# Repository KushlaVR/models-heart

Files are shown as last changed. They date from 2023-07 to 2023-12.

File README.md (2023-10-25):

# Model's Heart

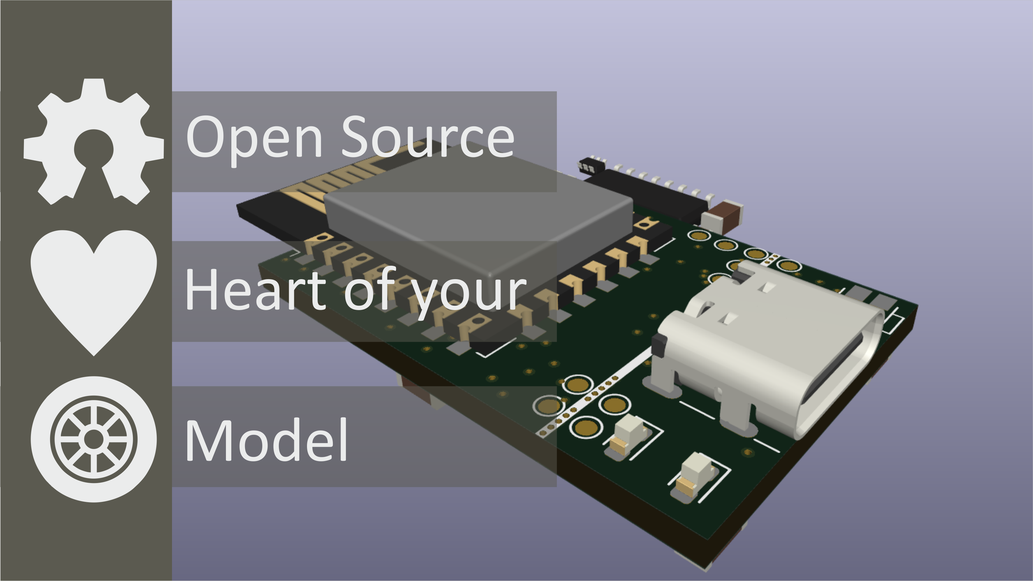
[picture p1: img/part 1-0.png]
Model's Heart View


## Breathe life into your model

Плата для керування електронікою моделі (статичної або рухомої)

Можливості:
* Керування через WIFI з телефона або ПК
* 5 незалежних каналів (світлодіоди/сервомотори)
* 1 Н-міст для підключення мотора (піковий струм до 3А)
* Вмонтована BMS 1S та контроллер заряду Li-Ion акумулятора з індикацією заряду
* Вмикання/вимикання 1 кнопкою (вже є на платі)
* Дистанційне вимкнення

# Поки ти читаєш цей текст - українці гинуть від російських ракет.
# While you are reading this text, Ukrainians are dying from russian missiles.

Ти можеш перерахувати будь-яку суму на спеціальний рахунок Національного Банку України для допомоги збройним силам україни у протистоянні російському окупанту.

Навіть незначна сума може врятувати чиєсь життя!

You can transfer any amount to a special account of the National Bank of Ukraine to help the armed forces of Ukraine in the fight against the Russian occupier.

Even a small amount can save someone's life!

### Для зарахування коштів у національній валюті:

```
Банк: Національний банк України
МФО 300001
Рахунок № UA843000010000000047330992708
код ЄДРПОУ 00032106
Отримувач: Національний банк України 
```
### To deposit funds in USD: 
```
BENEFICIARY: National Bank of Ukraine
BENEFICIARY BIC: NBUA UA UX
BENEFICIARY ADDRESS: 9 Instytutska St, Kyiv, 01601, Ukraine
ACCOUNT NUMBER: 804790258
BENEFICIARY BANK NAME: JP MORGAN CHASE BANK, New York
BENEFICIARY BANK BIC: CHASUS33
ABA 0210 0002 1
BENEFICIARY BANK ADDRESS: 383 Madison Avenue, New York, NY 10017, USA
PURPOSE OF PAYMENT: for ac 47330992708 
```
### To deposit funds in EUR: 
```
BENEFICIARY: National Bank of Ukraine
IBAN DE05504000005040040066
PURPOSE OF PAYMENT: for ac 47330992708
BENEFICIARY BANK NAME: DEUTSCHE  BUNDESBANK, Frankfurt
BENEFICIARY BANK BIC: MARKDEFF
BENEFICIARY BANK ADDRESS: Wilhelm-Epstein-Strasse 14, 60431 Frankfurt Am Main, Germany
```
### To deposit funds in GBP: 
```
BENEFICIARY/RECIPIENT NAME: National Bank of Ukraine
ACCOUNT NUMBER: 80033041
IBAN GB52CHAS60924280033041
BENEFICIARY ADDRESS: 9 Instytutska St, Kyiv, 01601, Ukraine
BENEFICIARY BANK NAME: JP MORGAN CHASE BANK NA, London
BENEFICIARY BANK BIC: CHASGB2L
SORT CODE: 60-92-42 
BENEFICIARY BANK ADDRESS: 125 London Wall, London EC2Y 5AJ, UK
PURPOSE OF PAYMENT: for ac 47330992708
```

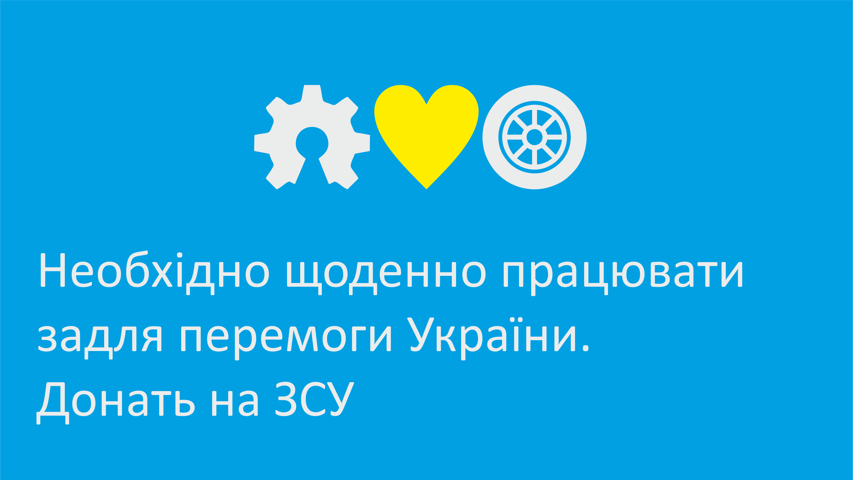
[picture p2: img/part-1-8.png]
Донатьте на ЗСУ


## Як створювалась ця плата

https://www.youtube.com/watch?v=I-fucbyPBxc&list=PLNvbguf8aVrykSSVMaIyB5YiUsczeTyt5

Цей список відтворення містить детальний опис процесу проектування, виготовлення та створення прошивки для цього проекту з чистого листка.

# Schematic

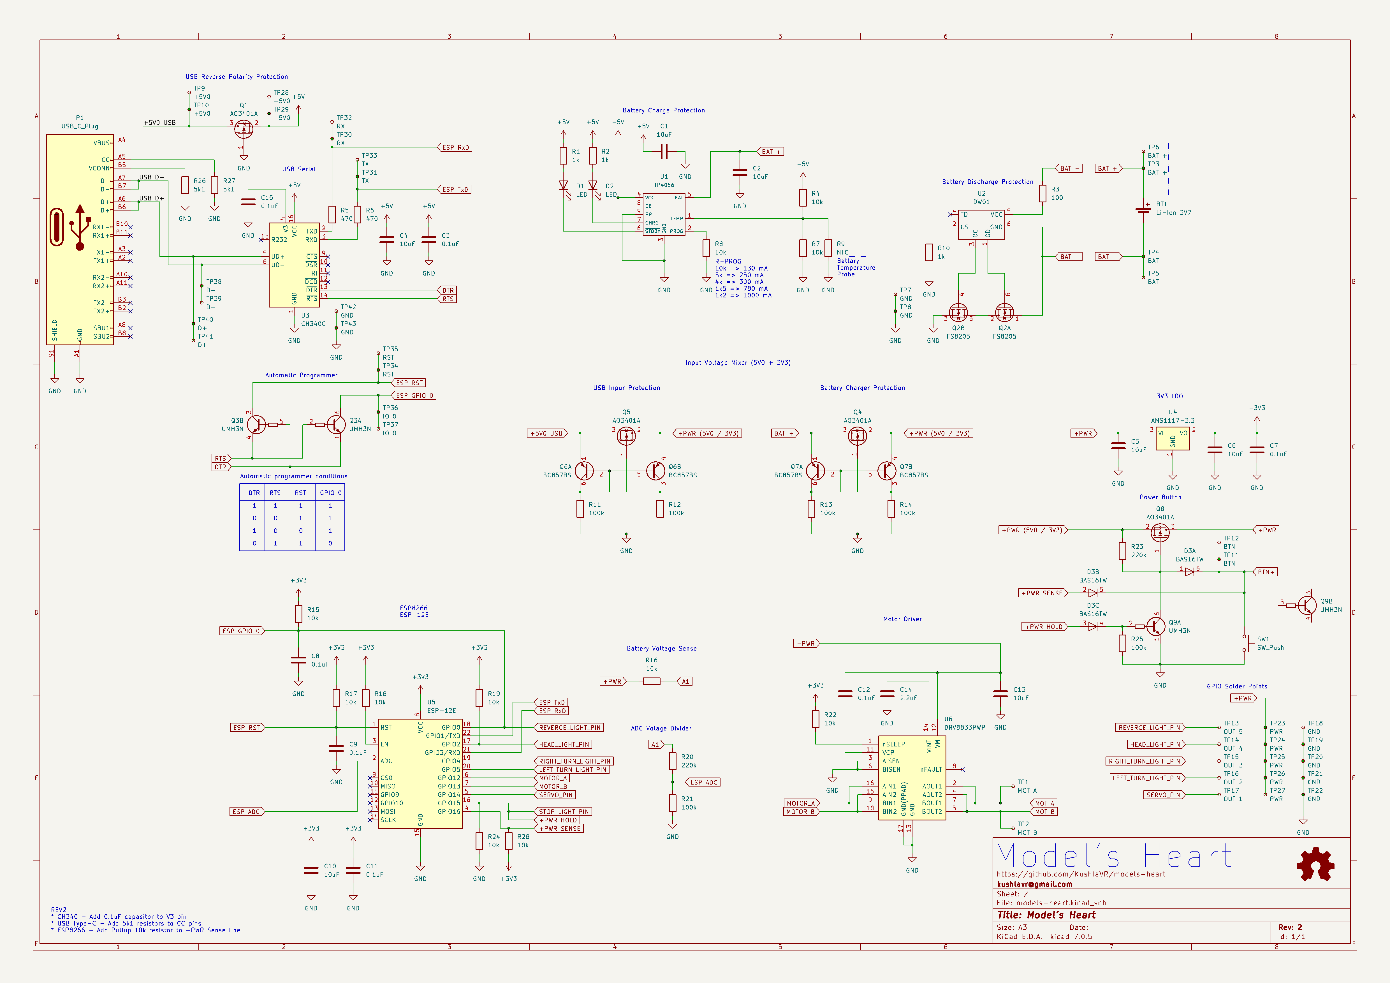
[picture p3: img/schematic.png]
Model's Heart Schematic


# Board

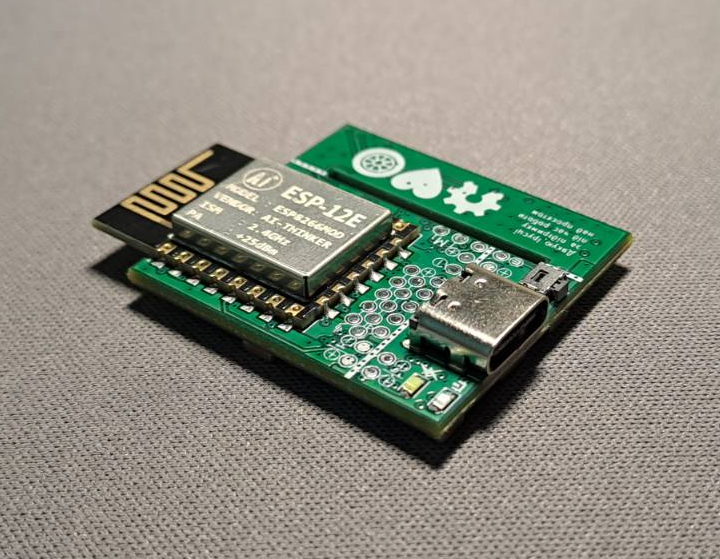
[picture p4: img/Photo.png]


# Що обрати Model's Heart чи Arduino?

Плата Model's Heart та Arduino  чи Wemos не є взаємозамінні. Вони схожі, проте мають і відмінності. Це як комп'ютери із різною комплектацією. 
Для коащого розуміння ознайомтесь із порівняльоню таблицею.

## Проівняльна таблиця Arduino Nano, Wemos D1, Model's Heart
| Характеристика |Arduino Nano | Wemos D1 | Model's Heart |
|--- |---|---|---|
| Процесор |Atmega 328| ESP8266  | ESP8266 |
| Ядро | 8-bit AVR RISC | Tensilica L106 32-bit RISC | Tensilica L106 32-bit RISC |
| Тип | Microcontroller| Soc  | SoC |
|Оперативня пам'ять|2K bytes|50k bytes|50k bytes|
|Постійна пам'ять|32K bytes інтергрована| - | - |
|Зовнішня пам'ять| - | 16M bytes | 16M bytes |
|Частота процесора| 16MHz | 52MHz | 52Mhz |
|GPIO| 24 | 11 | 8 |
|Analog Pins| 8 | 1 | 1 |
|ADC| 1 | 1 | 1 |
|Точність ADC | 10bit | 10bit | 10bit |
|Wi-Fi | - | 2.4GHz | 2.4GHz |
|USB Power | micro USB | micro USB | Type-C |
|Живлення від Li-Ion | - | - | + |
|Li-Ion BMS | - | - | + |
|Li-Ion Charger | - | - | + |
|Power switch | - | - | + |
|H-Bridge | - | - | 3A (max) |

## У мене вже є плата Model's Heart, що далі?
Базовий набір:
* Завантажена з GitHub копія проекту
* Модуль, або відлагоджувальна плата Model's Heart, або інша  на базі процесора ESP8266 (Наприклад Wemos D1 mini, Lolin, і т.п.)
* Комп'ютер з USB
* Веб-переглядач для налаштування (наприклад Edge, Chrome, Mozilla, Safari, Opera ...)

Додаткові інструменти, якщо ви захочете переробити прошивку під більш складні задачі:
* Visual Studio Code
* Встановлена бібліотека Platformio

## Прошивка
У папці Tools є утиліта для прошивки та безпосередньо сам файл прошивки. Для більшості користувачів цього є цілком достатньо. Виконавши декілька простих кроків, ви зможете перетворити плату у радіоапаратуру для керування моделями.

Покрокова інструкція
1. Підключаєте плату до USB-порту вашого комп'ютера.
2. Встановлюєте драйвер CH340 (якщо його ще немає)
3. Заходите у диспетчер пристроїв і перевіряєте, чи всі драйвери встановлено і чи ваша плата розпізнається системою. 
  * Відкриваєте панель керування комп'ютером. 
Call device manager
  * Переходите на пункт "Диспетчер пристроїв".
Ймовірно, ваша плата буде називатися 'USB-Serial CH340 (COM_)'
Model's Heart serial port
  * Запам'ятовуєте, який номер порта отримала ваша плата (у моєму випадку - №3)
Call device manager
4. Запускаєте Tools/upload.bat
5. Після старту скрипт запитає номер порта, до якого під'єднано вашу плату
6. Вводите номер (тільки цифру), натискаєте Enter
7. Натискаєте кнопку Power на платі Model's Heart
8. Чекаєте, поки завершиться процес завантаження

Все - плата прошита.

З цього моменту нею можна користуватись.

## Встановлення поновлень
Поновлення відбувається аналогічно до прошивки. Завантажуєте нову версію репозиторію. А далі все по кроках...

Зважте на те, що прошивка повністю переписує все що є в пам'яті плати. Тобто, якщо ви завантажували в неї модифікації через файловий менеджер, то завантажте їх, щоб не втратити.

# Налаштування елементів UI
Усі елементи користувацького інтерфейсу використовують абсолютну координатну сітку.
Відлік координат починається у верхньому правому кутку.

Робоче поле має фіксовані пропорції 100:45

Розміри елементів інтерфейсу вказуються у відсотковому еквіваленті до ширини робочого поля.

Наприклад цей текстовий блок буде розміщений з відступом 10% з ліва, 20% з гори. Його ширина і висота відповідатимуть відповідно 30% ширини екрану та 40% ширини екрану. Зверніть увагу, що в обидвох випадках (ширина і висота блока) виміри прив'язані до % **ширини екрану**
```
    {
        "type":"text",
        "x": "10",
        "y": "20",
        "w": "30",
        "h": "40",
        "text":"текст"
    }
```

## Елементи графічного інтерфейсу
## Text

```
    {
        "type":"text",
        "x": int,
        "y": int,
        "w": int,
        "h": int,
        "text":string,
        "bg":string
    }
```

## Button
```
    {
        "type":"button",
        "x": int,
        "y": int,
        "w": int,
        "h": int,
        "text": string,
        "cmd": string
    }
```

## Slider
```
    {
        "type":"slider",
        "x": int,
        "y": int,
        "w": int,
        "h": int,
        "color": string,
        "cmd": string,
        "autocenter": bool,
    }
```

## Image
```
    {
        "type":"image",
        "x": int,
        "y": int,
        "w": int,
        "h": int,
        "cmd": string,
        "src": string,
        "autocenter": bool,
    }
```

## Toggle
```
    {
        "type":"toggle",
        "x": int,
        "y": int,
        "w": int,
        "h": int,
        "text": "Off|A|B|C",
        "values": "0|30|60|90",
        "cmd": string,
        "autocenter": bool,
    }
```

## Редактор графічного інтерфейсу
Плата обладнана редактором інтерфейсу. З допомого якого можна вносити зміни в існуючий дизайн, або створититповністю новий унікальний вигляд на ваш смак.
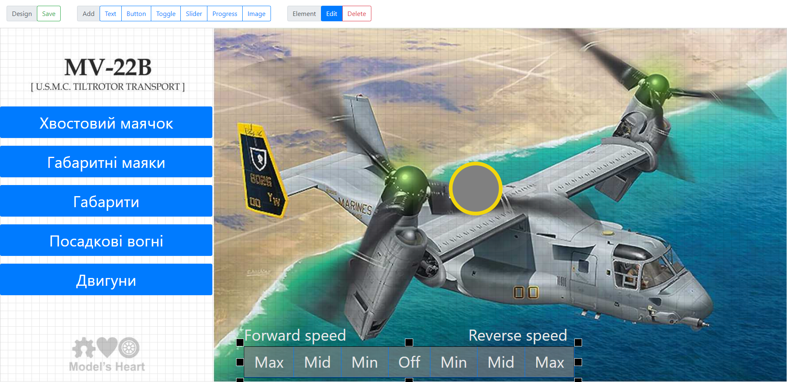
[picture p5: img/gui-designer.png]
Model's Heart GUI Designer


Для кожного елемента графічного інтерфейсу передбачено редактор властивостей.
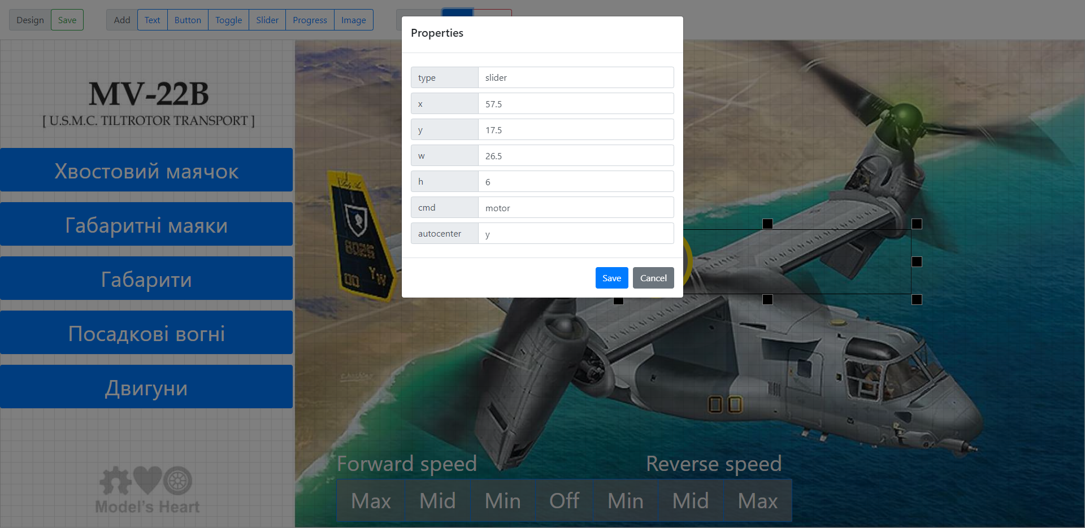
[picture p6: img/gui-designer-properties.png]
Model's Heart GUI Designer


## Графічний інтерфейс

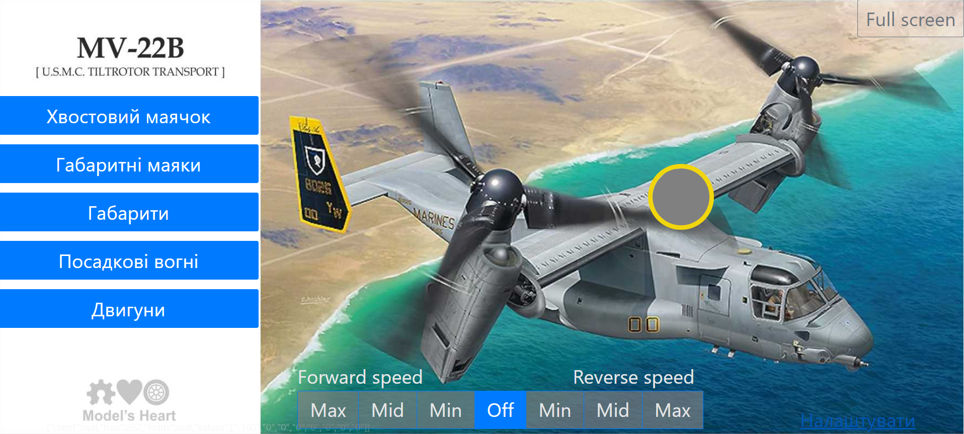
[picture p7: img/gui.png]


## Сценарій

Сценарій визначає, як плата реагуватиме на команди користувача. У сценарію є лише одна властивість - "elements" (містить перелік команд)

```
{
    "elements" : [ {"cmd": string, ..}, {..}, ..]
}
```

Команди активуються у результаті взаємодії користувач з UI. Поки команда активна - її дії обробляються, інакше - ігноруються.

Структура команди:

- cmd - назва команди.
- type - тип команди
  * toggle - кожна активація команди вмикає/вимикає її стан
  * click - команда активна поки користувач утримує її значення відмінним від 0
  * none - команда не потребує активації. Вона активна завжди.
- actions - перелік дій, що будуть виконуватись поки команда активна.

```
{
    "cmd": string,
    "type": "toggle/click/none",
    "actions": 
        [
            {
                "type": 
                "cmd": string,
            },
            {
                "type": "motor",
                "speed": string (source of speed value for full H bridge). When set - a+b ignored
                "a": string (source of A half bridge values),
                "b": string (source of B half bridge values),
                "weight": int (in grams)
            },
            {
                "type": "blink",
                "points": [
                    {"pin": "1", "offset":"0", "value":"0"},
                    {"pin": "1", "offset":"500", "value":"255"},
                    {"pin": "1", "offset":"1000", "value":"0"}
                ]
            }
        ...
        ]
}
```
### Дії сценаріїв

#### Маячок
Дія перемикає виходи у заданій часовій точці.

- type - blink
- points - масив точок

Точка:
- pin - номер виходу
- offset - точка часу у мілісекундах. Відлік починається від старту дії
- value - PWM значення виходу

```
{
    "type": "blink",
    "points": [
        {"pin": "1", "offset":"0", "value":"0"},
        {"pin": "1", "offset":"500", "value":"255"},
        {"pin": "1", "offset":"1000", "value":"0"}
    ]
}
```

#### Мотор
Дія використовується для керування мотором.

- type - motor
- speed - назва команди яка використовуються для швидкості мотора
- weight - вага уявного маховика мотора. Використовується для імітації інерції

```
{
    "type":"motor",
    "speed":"motor_x",
    "weight": "80000"
}
```

## Приклади сценаріїв
### Керування гвинтовим літаком

ui.json
```
{
  "bg": "url('img/bg.jpg')",
  "elements": [
    {
      "type": "toggle",
      "x": 31,
      "y": 40.5,
      "w": 42,
      "h": 4,
      "text": "Max|Mid|Min|Off|Min|Mid|Max",
      "cmd": "motor_x",
      "values": "100|60|30|0|-30|-60|-100"
    },
    {
      "type": "slider",
      "x": 57.5,
      "y": 17.5,
      "w": 26.5,
      "h": 6,
      "cmd": "motor",
      "autocenter": "y"
    },
    {
      "type": "button",
      "x": 0,
      "y": 10,
      "w": 27,
      "h": 4,
      "text": "Хвостовий маячок",
      "cmd": "beacon"
    },
    {
      "type": "button",
      "x": 0,
      "y": 15,
      "w": 27,
      "h": 4,
      "text": "Габаритні маяки",
      "cmd": "strobe"
    },
    {
      "type": "button",
      "x": 0,
      "y": 20,
      "w": 27,
      "h": 4,
      "text": "Габарити",
      "cmd": "position"
    },
    {
      "type": "button",
      "x": 0,
      "y": 25,
      "w": 27,
      "h": 4,
      "text": "Посадкові вогні",
      "cmd": "navigation"
    },
    {
      "type": "button",
      "x": 0,
      "y": 30,
      "w": 27,
      "h": 4,
      "text": "Двигуни",
      "cmd": "ignition"
    },
    {
      "type": "text",
      "x": 31,
      "y": 37.5,
      "w": 18,
      "h": 3,
      "text": "Forward speed",
      "cmd": ""
    },
    {
      "type": "text",
      "x": 59.5,
      "y": 37.5,
      "w": 13.5,
      "h": 3,
      "text": "Reverse speed",
      "cmd": ""
    },
    {
      "text": "null",
      "cmd": "motor_x",
      "type": "image",
      "x": 46.5,
      "y": 14,
      "w": 10,
      "h": 10,
      "src": "img/green.png"
    },
    {
      "text": "null",
      "cmd": "motor_x",
      "type": "image",
      "x": 78.5,
      "y": 2,
      "w": 10,
      "h": 10,
      "src": "img/green.png"
    }
  ]
}
```

scripts.json
```
{
  "elements": [
    {
      "cmd": "beacon",
      "type": "toggle",
      "actions": [
        {
          "type": "blink",
          "points": [
            {
              "pin": "1",
              "offset": "0",
              "value": "0"
            },
            {
              "pin": "1",
              "offset": "0",
              "value": "0"
            },
            {
              "pin": "1",
              "offset": "100",
              "value": "20"
            },
            {
              "pin": "1",
              "offset": "200",
              "value": "50"
            },
            {
              "pin": "1",
              "offset": "300",
              "value": "90"
            },
            {
              "pin": "1",
              "offset": "400",
              "value": "50"
            },
            {
              "pin": "1",
              "offset": "500",
              "value": "20"
            },
            {
              "pin": "1",
              "offset": "600",
              "value": "0"
            },
            {
              "pin": "1",
              "offset": "1000",
              "value": "0"
            }
          ]
        }
      ]
    },
    {
      "cmd": "strobe",
      "type": "toggle",
      "actions": [
        {
          "type": "blink",
          "points": [
            {
              "pin": "4",
              "offset": "0",
              "value": "0"
            },
            {
              "pin": "4",
              "offset": "0",
              "value": "255"
            },
            {
              "pin": "4",
              "offset": "100",
              "value": "0"
            },
            {
              "pin": "4",
              "offset": "300",
              "value": "255"
            },
            {
              "pin": "4",
              "offset": "400",
              "value": "0"
            },
            {
              "pin": "4",
              "offset": "1000",
              "value": "0"
            }
          ]
        }
      ]
    },
    {
      "cmd": "position",
      "type": "toggle",
      "actions": [
        {
          "type": "blink",
          "points": [
            {
              "pin": "3",
              "offset": "0",
              "value": "0"
            },
            {
              "pin": "3",
              "offset": "0",
              "value": "255"
            },
            {
              "pin": "3",
              "offset": "1000",
              "value": "255"
            }
          ]
        }
      ]
    },
    {
      "cmd": "navigation",
      "type": "toggle",
      "actions": [
        {
          "type": "blink",
          "points": [
            {
              "pin": "2",
              "offset": "0",
              "value": "0"
            },
            {
              "pin": "2",
              "offset": "0",
              "value": "255"
            },
            {
              "pin": "2",
              "offset": "1000",
              "value": "255"
            }
          ]
        }
      ]
    },
    {
      "cmd": "ignition",
      "type": "toggle",
      "actions": [
        {
          "type":"motor",
          "speed":"motor_x",
          "weight": "80000"
        }
      ]
    }
  ]
}
```

# Підключення

## Чи можна розрізати плату?
Плата достатньо мініатюрна і необхідно постаратись її так прилаштувати, щоб не довелось її розрізати. Проте, якщо є необхідність "запакувати" по максимуму, то плату можна розрізати на 3 окремі частини. Після розрізання, їх можна об'єднати провідниками, або використовувати плату без них. Кожна із 3-ох частин є завершеним блоком.

How to cut PCB Model's Heart in correct way

## Підключення окремих блоків плати Model's Heart
### Плата зарядки
Плата зарядки - може використовуватись як зарядний пристрій Li-Ion акумуляторів.

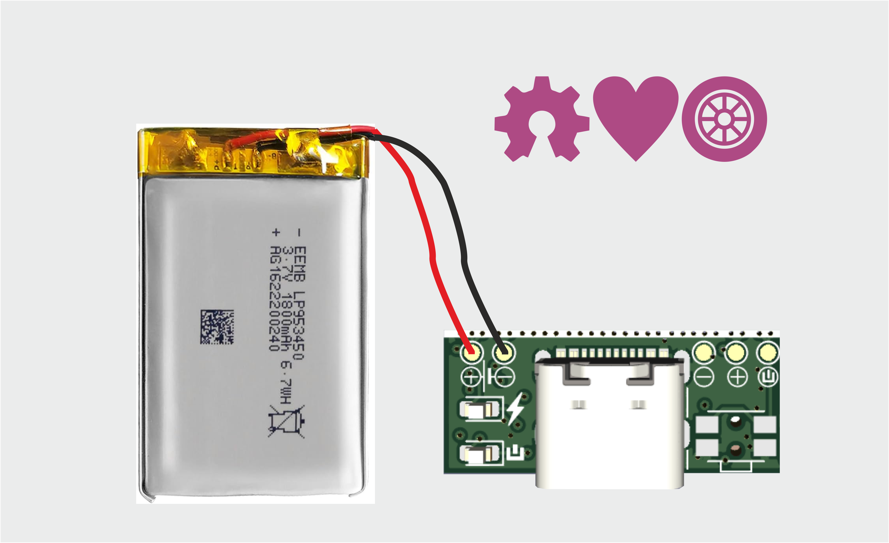
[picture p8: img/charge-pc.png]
Charging chunk


### Плата програматора

Плату програматора можна використовувати як окремий USB<->TTL перетворювач.

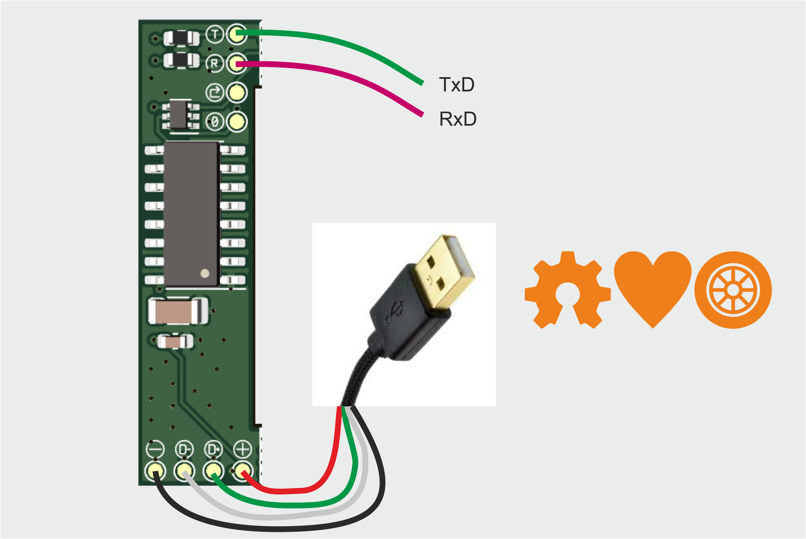
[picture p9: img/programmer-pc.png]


### Основна плата
#### Підключення акумулятора
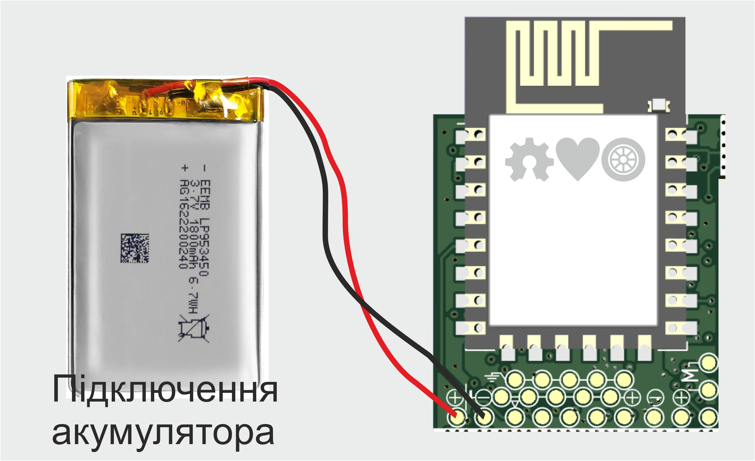
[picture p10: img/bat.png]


#### Підключення мотора
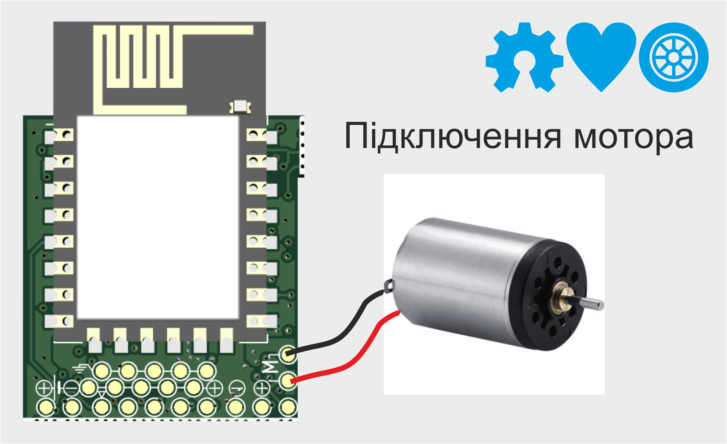
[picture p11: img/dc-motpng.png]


#### Підключення кнопки вкл./викл.
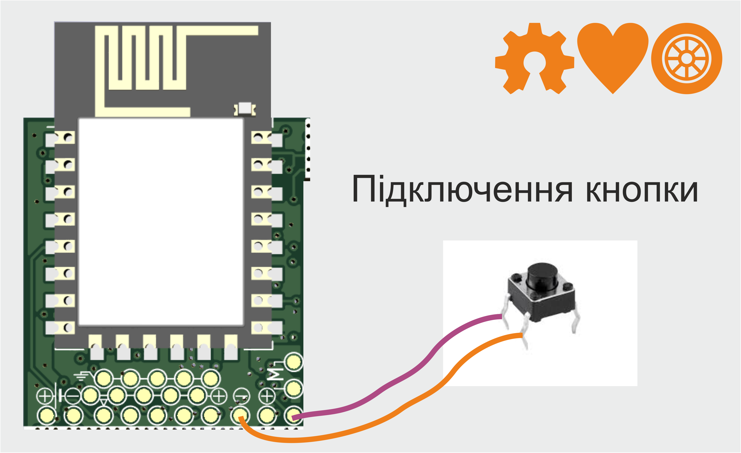
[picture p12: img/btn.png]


#### Підключення світлодіода до виходу #1

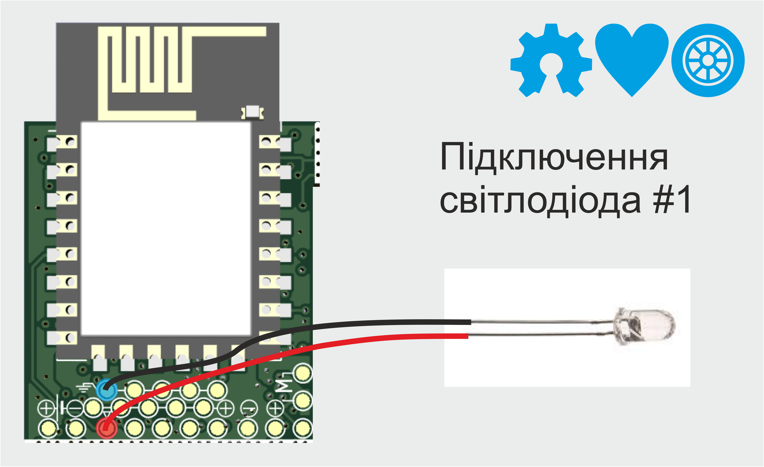
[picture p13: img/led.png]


#### Підключення світлодіода до шини живлення #2
При підключенні світлодіода до шини живлення необхідно обмежити струм з допомогою резистора. Типовий струм для світлодіодів - 2мА

Опір обмежувального резистора можна розрахувати за законом Ома

```
Закон Ома

  I = U/R 

Де:
  I - струм, що протікає через коло в Амперах
  U - напруга на кінцях кола у Вольтах
  R - опір кола у Омах

Знаходимо R

  R = U/I 

  U = 4.2V
  I = 2mA = 0.002A

  R = 4.2V / 0.002A 
  R = 2100 Ом => 2.1KOм

```

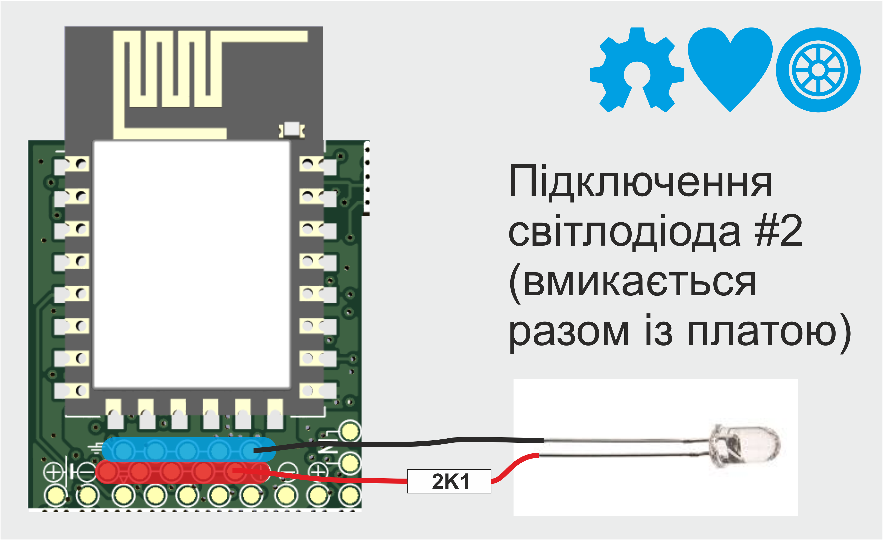
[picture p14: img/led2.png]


# Web API

Взаємодія web інтерфейсу та плати відбувається по WIF з допомогою HTTP запитів.

Плата Model's Heart дозволяє одночасне керування з кількох клієнтів.
Для того, щоб надіслані команди відпрацьовувались платою - необхідна авторизація (GET api/EventSourceName). У відповідь ми отримаємо endpoint з допомогою якого можна підписатись на HTTP Events (GET /api/events), щоб отримувати інформацію від плати. Також, щоразу як користувач змінив стан поля відбувається пересилка цього стану у плату (POST api/post)

## GET api/EventSourceName
Метод повертає Endpoint (адресу джерела Events) по якому транслюється інформація з плати на web-UI. Одним із параметрів є ID клієнта

## GET /api/events 
Встановлюється як EventSource для сторінки Web інтерфейсу
Детальніше тут ->  https://developer.mozilla.org/en-US/docs/Web/API/EventSource

## POST api/post
Надсилаємо інформацію про поле на плату
```
{
  client:"random string id of client"
  format:[field1, field2, field, ... fieldN],
  values:['v1', 'v2', 'v3', .. 'vN']
}
```

- client - ID клієнта
- format - назви полів які наявні у інтерфейсі. Надсилається лише один раз. Всі інші рази ігнорується. Цього формату має притримуватись додаток при комунікації з приладом, і в такому ж форматі має відповідати плата. (це для того, щоб мінімізувати трафік і одночасно забезпечити підтримку стрих версій додатку у яких може бути інша конфігурація елементів керування)
- values - значення полів у посортовані відповідно до format.

## Алгоритм взаємодії
1. Авторизація
2. Налаштовуємо EventSource. 
3. POST api/post формат даних
4. По Event source каналу отримуємо від плати масив значень і розставляємо їх по елементах керування у відповідності до обговореного формату
5. Якщо користувач змінив якийсь параметр - надсилаємо платі пакет у обговореному наперед форматі. (Повертаємось до п4)
6. Якщо зв'язок втрачено - запускаємо зворотній відлік на 3 секунди і пробуємо відновити зв'язок (Повертаємось до п1)

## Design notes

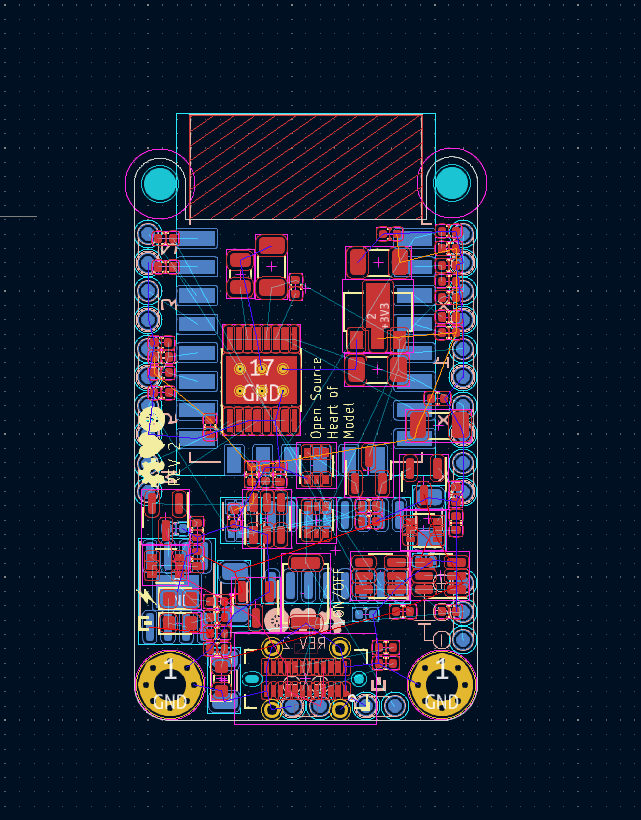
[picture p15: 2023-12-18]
img/3D-rev2-pcb.png

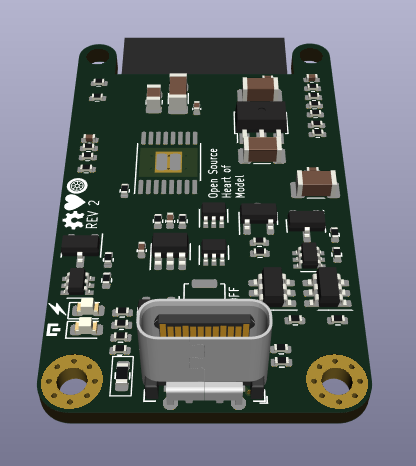
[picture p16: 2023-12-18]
img/3D-rev2-bot.png

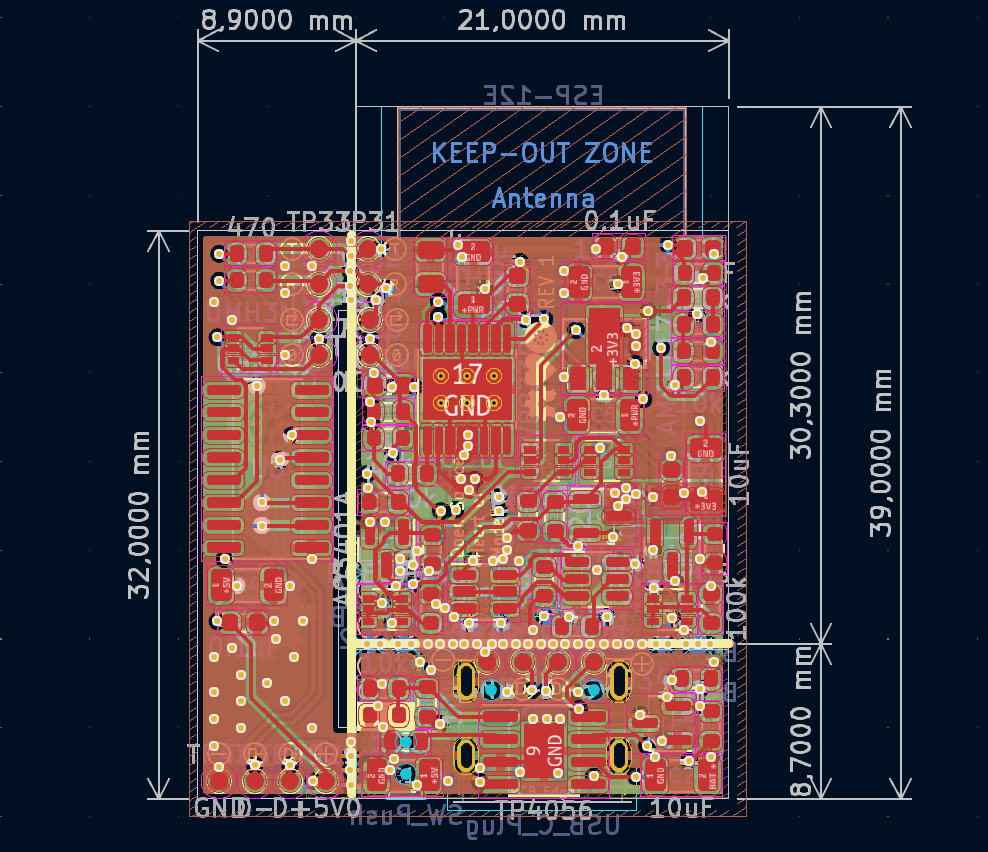
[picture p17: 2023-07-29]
img/PCB.png

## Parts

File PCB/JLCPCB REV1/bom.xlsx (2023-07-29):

Comment | Designator | Footprint | JLCPCB Part # | Quantity
FS8205 | Q2 | Package_TO_SOT_SMD:SOT-23-6 | C908265 | 1
UMH3N | Q3, Q9 | Package_TO_SOT_SMD:SOT-363_SC-70-6 | C62892 | 2
BC857BS | Q6, Q7 | Package_TO_SOT_SMD:SOT-363_SC-70-6 | C699266 | 2
1k | R1, R2, R10 | Resistor_SMD:R_0603_1608Metric | C21190 | 3
100 | R3 | Resistor_SMD:R_0603_1608Metric | C22775 | 1
10k | R4, R7, R8, R15, R16, R17, R18, R19, R22, R24 | Resistor_SMD:R_0603_1608Metric | C25804 | 10
470 | R5, R6 | Resistor_SMD:R_0603_1608Metric | C23179 | 2
100k | R11, R12, R13, R14, R21, R25 | Resistor_SMD:R_0603_1608Metric | C25803 | 6
220k | R20, R23 | Resistor_SMD:R_0603_1608Metric | C22961 | 2
10uF | C1, C2, C4, C5, C6, C10, C13 | Capacitor_SMD:C_1206_3216Metric | C13585 | 7
SW_Push | SW1 | Button_Switch_SMD:SW_SPST_EVQP7C | C115362 | 1
0.1uF | C3, C7, C8, C9, C11, C12 | Capacitor_SMD:C_0603_1608Metric | C913910 | 6
2.2uF | C14 | Capacitor_SMD:C_0805_2012Metric | C49217 | 1
TP4056 | U1 | Package_SO:SOIC-8-1EP_3.9x4.9mm_P1.27mm_EP2.29x3mm | C16581 | 1
DW01 | U2 | Package_TO_SOT_SMD:SOT-23-6 | C917079 | 1
CH340C | U3 | Package_SO:SOIC-16_3.9x9.9mm_P1.27mm | C84681 | 1
AMS1117-3.3 | U4 | Package_TO_SOT_SMD:SOT-89-3 | C880752 | 1
ESP-12E | U5 | RF_Module:ESP-12E | C89297 | 1
DRV8833PWP | U6 | Package_SO:HTSSOP-16-1EP_4.4x5mm_P0.65mm_EP3.4x5mm_Mask2.46x2.31mm_ThermalVias | C50506 | 1
LED | D1 | LED_SMD:LED_0603_1608Metric | C2286 | 1
LED | D2 | LED_SMD:LED_0603_1608Metric | C2290 | 1
BAS16TW | D3 | Package_TO_SOT_SMD:SOT-363_SC-70-6 | C68955 | 1
USB_C_Plug | P1 | Connector_USB:USB_C_Receptacle_GCT_USB4105-xx-A_16P_TopMnt_Horizontal | C2927038 | 1
AO3401A | Q1, Q4, Q5, Q8 | Package_TO_SOT_SMD:SOT-23 | C15127 | 4

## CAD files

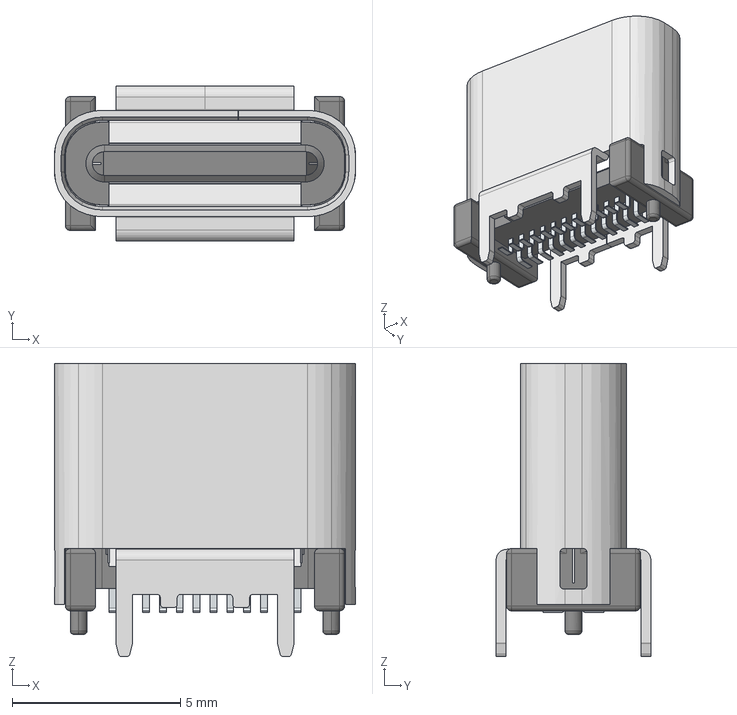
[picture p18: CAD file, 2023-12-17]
PCB/symdol_lib/step/632722110112.stp
8.94 x 4.60 x 8.71 mm

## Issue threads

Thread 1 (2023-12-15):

Плата зависає під час включення.

KushlaVR, 2023-12-15:
Після включення плата зависає, і її неможливо вимкнути. Щоб вивести її з такого стану доводиться її перепрошивати.

KushlaVR, 2023-12-15:
Така проблема існує.
Це пов'язано із тим, що при розряді акумулятора нижче 3,2В процесор не може працювати адекватно. Цей баг буде вирішено у наступних ревізіях.
Щоб вивести плату з такого стану необхідно
1. підключити її до ком'пютера.
2. pозпочати прошивку, але не утримувати кнопку power.
3. плата вимкнеться.
Перед наступним вмиканням слід повністю зарядити акумулятор.

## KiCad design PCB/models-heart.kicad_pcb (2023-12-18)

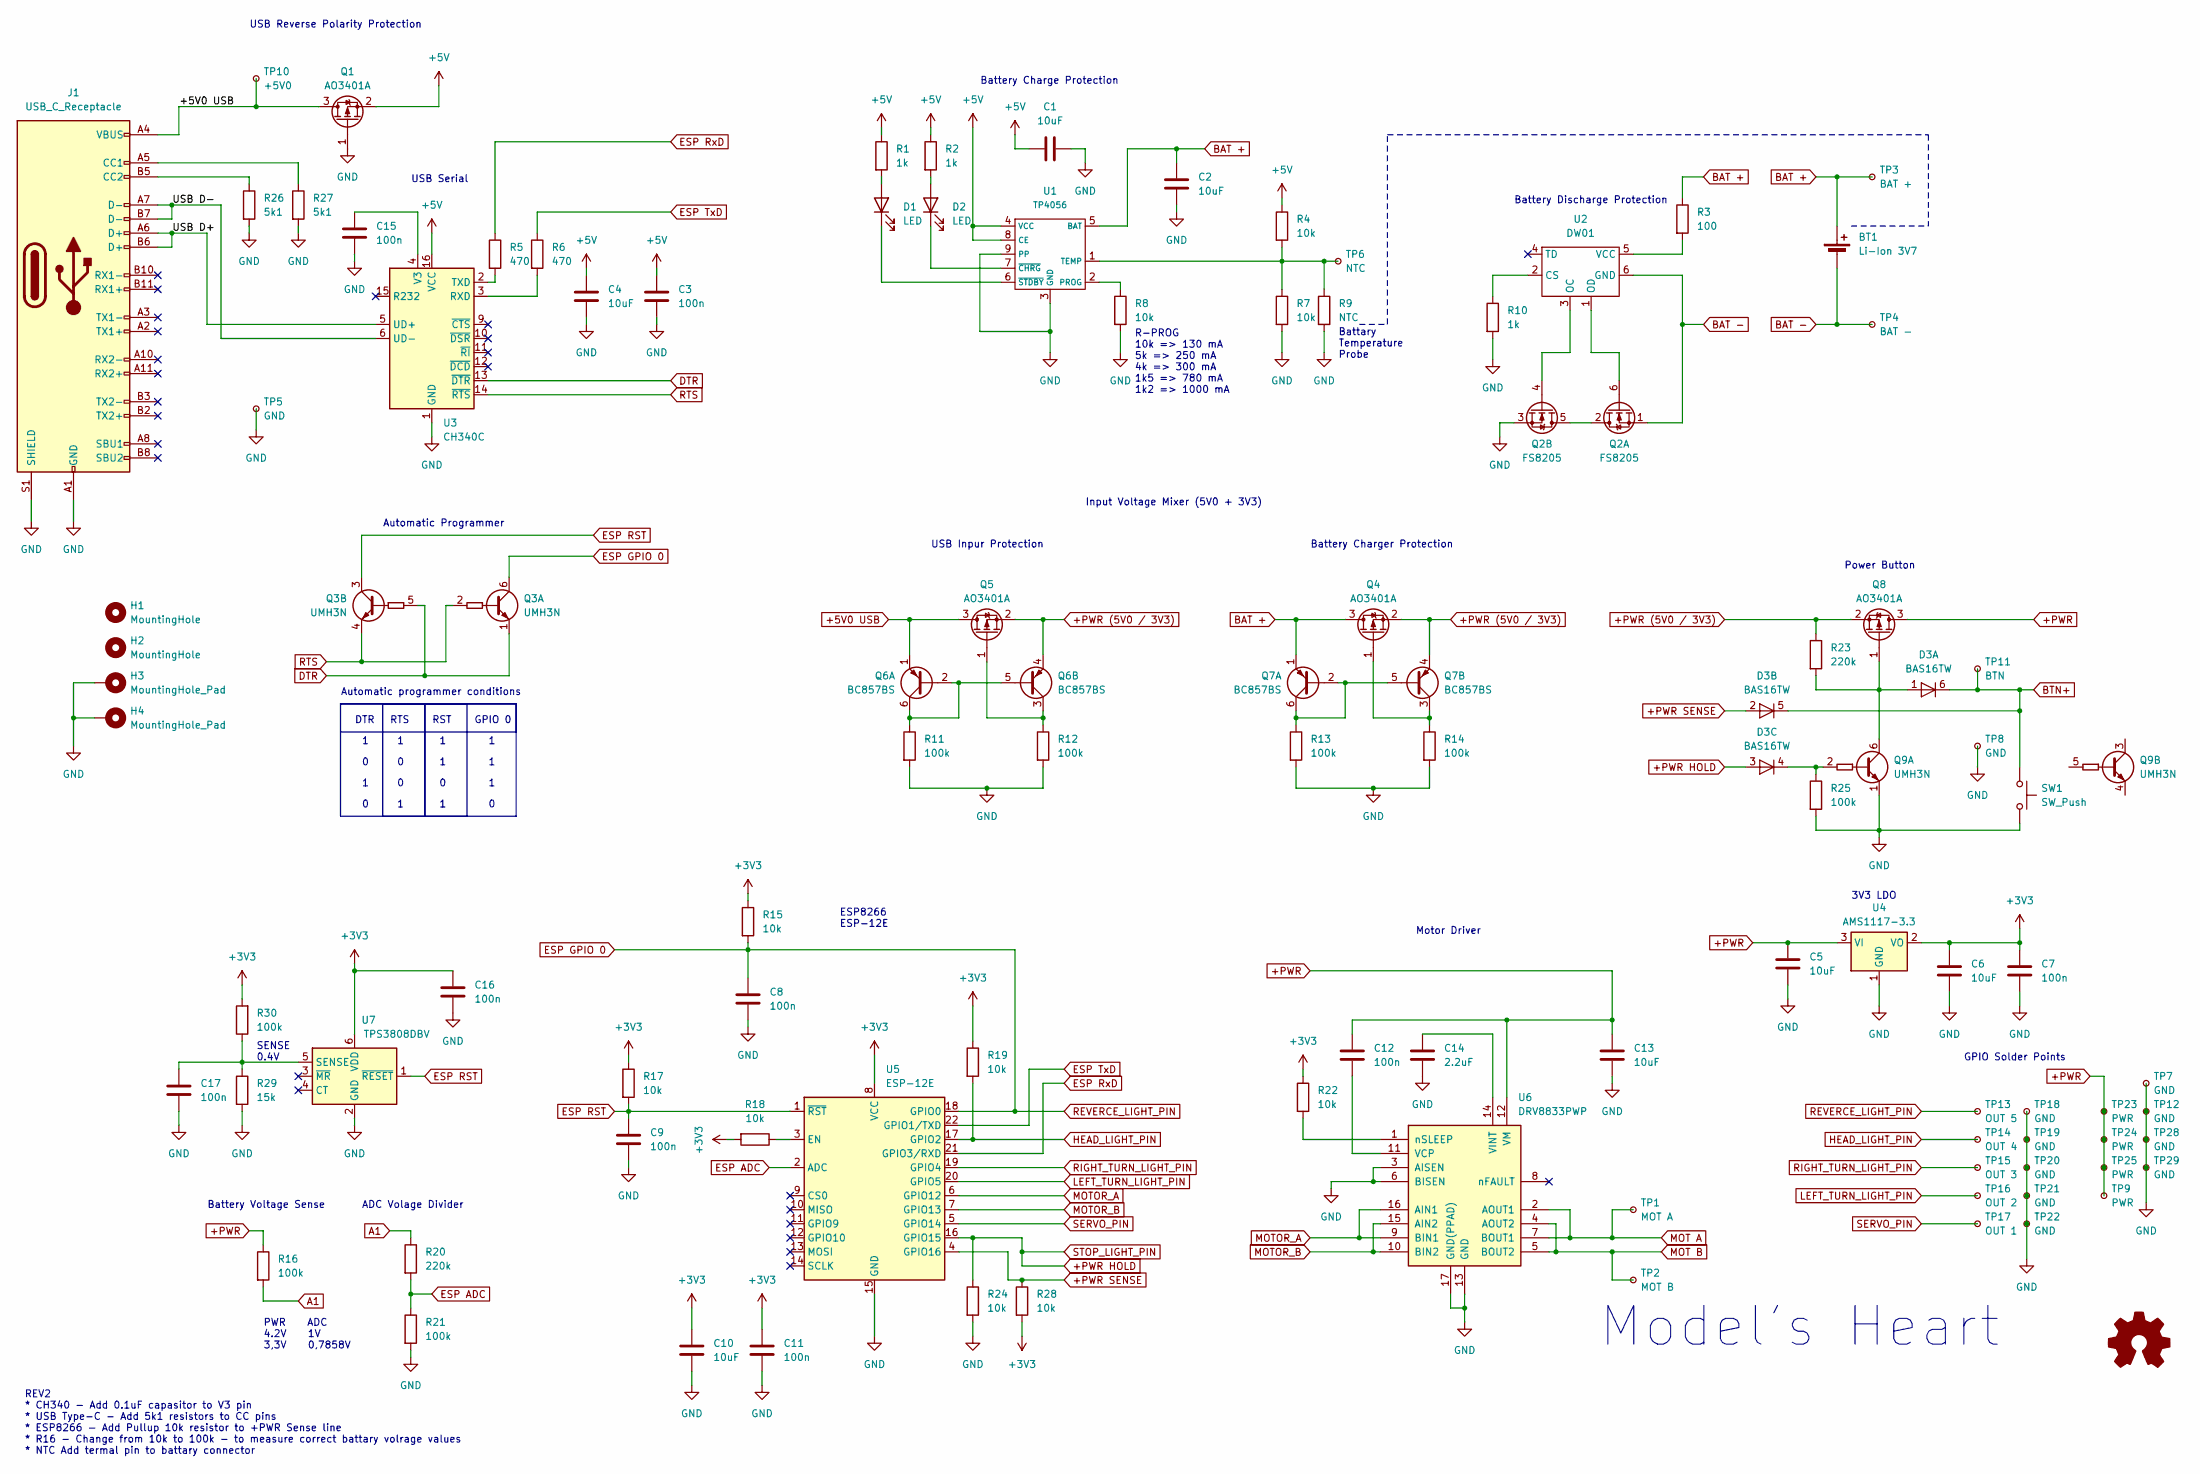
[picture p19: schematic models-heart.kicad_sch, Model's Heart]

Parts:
BT1: Li-Ion 3V7
C1, C2, C4, C5, C6, C10, C13: 10uF; C_1206_3216Metric; LCSC C13585
C3, C7, C8, C9, C11, C12, C15, C16, C17: 100n; C_0402_1005Metric; LCSC C307331
C14: 2.2uF; C_0805_2012Metric; LCSC C49217
D1: LED; LED_0603_1608Metric; LCSC C2286
D2: LED; LED_0603_1608Metric; LCSC C2290
D3: BAS16TW; SOT-363_SC-70-6; LCSC C68955
H1, H2: MountingHole; MountingHole_2.2mm_M2
H3, H4: MountingHole_Pad; MountingHole_2.2mm_M2_Pad_Via
J1: USB_C_Receptacle; USB_C_Receptacle_GCT_USB4115-03-C; LCSC C3039318
Q1, Q4, Q5, Q8: AO3401A; SOT-23; LCSC C15127
Q2: FS8205; SOT-23-6; LCSC C908265
Q3, Q9: UMH3N; SOT-363_SC-70-6; LCSC C62892
Q6, Q7: BC857BS; SOT-363_SC-70-6; LCSC C699266
R1, R2, R10: 1k; R_0402_1005Metric; LCSC C21190
R3: 100; R_0402_1005Metric; LCSC C22775
R4, R7, R8, R15, R17, R18, R19, R22, R24, R28: 10k; R_0402_1005Metric; LCSC C25804
R5, R6: 470; R_0402_1005Metric; LCSC C23179
R9: NTC; R_0603_1608Metric
R11, R12, R13, R14, R16, R21, R25, R30: 100k; R_0402_1005Metric; LCSC C25803
R20, R23: 220k; R_0402_1005Metric; LCSC C22961
R26, R27: 5k1; R_0402_1005Metric; LCSC C23186
R29: 15k; R_0402_1005Metric; LCSC C25804
SW1: SW_Push; SW_Push_SPST_NO_Alps_SKRK; LCSC C2905174
TP1: MOT A; TestPoint_Pad_D1.0mm
TP2: MOT B; TestPoint_Pad_D1.0mm
TP3: BAT +; TestPoint_Pad_D1.0mm
TP4: BAT -; TestPoint_Pad_D1.0mm
TP5, TP7, TP8, TP12, TP18, TP19, TP20, TP21, TP22, TP28, TP29: GND; TestPoint_Pad_D1.0mm
TP6: NTC; TestPoint_Pad_D1.0mm
TP9, TP23, TP24, TP25: PWR; TestPoint_Pad_D1.0mm
TP10: +5V0; TestPoint_Pad_D1.0mm
TP11: BTN; TestPoint_Pad_D1.0mm
TP13: OUT 5; TestPoint_Pad_D1.0mm
TP14: OUT 4; TestPoint_Pad_D1.0mm
TP15: OUT 3; TestPoint_Pad_D1.0mm
TP16: OUT 2; TestPoint_Pad_D1.0mm
TP17: OUT 1; TestPoint_Pad_D1.0mm
U1: TP4056; SOIC-8-1EP_3.9x4.9mm_P1.27mm_EP2.29x3mm; LCSC C16581
U2: DW01; SOT-23-6; LCSC C917079
U3: CH340C; SOIC-16_3.9x9.9mm_P1.27mm; LCSC C84681
U4: AMS1117-3.3; SOT-89-3; LCSC C880752
U5: ESP-12E; LCSC C89297
U6: DRV8833PWP; HTSSOP-16-1EP_4.4x5mm_P0.65mm_EP3.4x5mm_Mask2.46x2.31mm_The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; LCSC C50506
U7: TPS3808DBV; SOT-23-6; LCSC C19653

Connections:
+3V3: C6.1, C7.1, C10.1, C11.1, C16.1, R15.1, R17.1, R18.2, R19.1, R22.1, R28.2, R30.2, U4.2 (VO), U5.8 (VCC), U7.6 (VDD)
+5V: C1.1, C3.1, C4.1, Q1.2 (S), R1.1, R2.1, R4.1, U1.4 (VCC), U1.8 (CE), U3.16 (VCC)
+5V0 USB: J1.A4 (VBUS), J1.A9 (VBUS), J1.B4 (VBUS), J1.B9 (VBUS), Q1.3 (D), Q5.3 (D), Q6.1 (E1), TP10.1
+PWR: C5.1, C12.1, C13.1, Q8.3 (D), R16.1, TP9.1, TP23.1, TP24.1, TP25.1, U4.3 (VI), U6.12 (VM)
+PWR (5V0 / 3V3): Q4.2 (S), Q5.2 (S), Q6.4 (E2), Q7.4 (E2), Q8.2 (S), R23.1
+PWR HOLD: D3.3 (A), R24.1, U5.16 (GPIO15)
+PWR SENSE: D3.2 (A), R28.1, U5.4 (GPIO16)
/USB D+: J1.A6 (D+), J1.B6 (D+), U3.5 (UD+)
/USB D-: J1.A7 (D-), J1.B7 (D-), U3.6 (UD-)
A1: R16.2, R20.1
BAT +: BT1.1 (+), C2.2, Q4.3 (D), Q7.1 (E1), R3.1, TP3.1, U1.5 (BAT)
BAT -: BT1.2 (-), Q2.1 (S), TP4.1, U2.6 (GND)
BTN+: D3.5 (K), D3.6 (K), SW1.1, TP11.1
DTR: Q3.1 (E1), Q3.5 (B2), U3.13 (~DTR)
ESP ADC: R20.2, R21.1, U5.2 (ADC)
ESP GPIO 0: C8.1, Q3.6 (C1), R15.2, TP13.1, U5.18 (GPIO0)
ESP RST: C9.1, Q3.3 (C2), R17.2, U5.1 (~RST), U7.1 (~RESET)
ESP RxD: R5.1, U5.21 (GPIO3/RXD)
ESP TxD: R6.1, U5.22 (GPIO1/TXD)
GND: C1.2, C2.1, C3.2, C4.2, C5.2, C6.2, C7.2, C8.2, C9.2, C10.2, C11.2, C13.2, C14.2, C15.2, C16.2, C17.2, H3.1, H4.1, J1.A1 (GND), J1.A12 (GND), J1.B1 (GND), J1.B12 (GND), J1.S1 (SHIELD), Q1.1 (G), Q2.3 (S), Q9.1 (E1), R7.2, R8.2, R9.2, R10.2, R11.2, R12.2, R13.2, R14.2, R21.2, R24.2, R25.2, R26.2, R27.2, R29.2, SW1.2, TP5.1, TP7.1, TP8.1, TP12.1, TP18.1, TP19.1, TP20.1, TP21.1, TP22.1, TP28.1, TP29.1, U1.3 (GND), U1.9 (PP), U3.1 (GND), U4.1 (GND), U5.15 (GND), U6.3 (AISEN), U6.6 (BISEN), U6.13 (GND), U6.17 (GND(PPAD)), U7.2 (GND)
HEAD_LIGHT_PIN: R19.2, TP14.1, U5.17 (GPIO2)
LEFT_TURN_LIGHT_PIN: TP16.1, U5.20 (GPIO5)
MOT A: TP1.1, U6.2 (AOUT1), U6.7 (BOUT1)
MOT B: TP2.1, U6.4 (AOUT2), U6.5 (BOUT2)
MOTOR_A: U5.6 (GPIO12), U6.9 (BIN1), U6.16 (AIN1)
MOTOR_B: U5.7 (GPIO13), U6.10 (BIN2), U6.15 (AIN2)
unnamed: D1.2 (A), R1.2
unnamed: D1.1 (K), U1.6 (~STDBY)
unnamed: D2.2 (A), R2.2
unnamed: D2.1 (K), U1.7 (~CHRG)
unnamed: D3.1 (A), Q8.1 (G), Q9.6 (C1), R23.2
unnamed: D3.4 (K), Q9.2 (B1), R25.1
unnamed: J1.A5 (CC1), R27.1
unnamed: J1.B5 (CC2), R26.1
unnamed: Q2.2 (D), Q2.5 (D)
unnamed: Q2.6 (G), U2.1 (OD)
unnamed: Q2.4 (G), U2.3 (OC)
unnamed: Q4.1 (G), Q7.3 (C2), R14.1
unnamed: Q5.1 (G), Q6.3 (C2), R12.1
unnamed: Q6.2 (B1), Q6.5 (B2), Q6.6 (C1), R11.1
unnamed: Q7.2 (B1), Q7.5 (B2), Q7.6 (C1), R13.1
unnamed: R8.1, U1.2 (PROG)
unnamed: R4.2, R7.1, R9.1, TP6.1, U1.1 (TEMP)
unnamed: R10.1, U2.2 (CS)
unnamed: R3.2, U2.5 (VCC)
unnamed: R6.2, U3.3 (RXD)
unnamed: R5.2, U3.2 (TXD)
unnamed: C15.1, U3.4 (V3)
unnamed: R18.1, U5.3 (EN)
unnamed: C12.2, U6.11 (VCP)
unnamed: C14.1, U6.14 (VINT)
unnamed: R22.2, U6.1 (nSLEEP)
unnamed: C17.1, R29.1, R30.1, U7.5 (SENSE)
RIGHT_TURN_LIGHT_PIN: TP15.1, U5.19 (GPIO4)
RTS: Q3.2 (B1), Q3.4 (E2), U3.14 (~RTS)
SERVO_PIN: TP17.1, U5.5 (GPIO14)

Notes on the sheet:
Input Voltage Mixer (5V0 + 3V3)
Model's Heart
USB Reverse Polarity Protection
Battary Temperature Probe
RTS
DTR
ESP8266 ESP-12E
RST
Battery Charger Protection
ADC Volage Divider
REV2 * CH340 - Add 0.1uF capasitor to V3 pin * USB Type-C - Add 5k1 resistors to CC pins * ESP8266 - Add Pullup 10k resistor to +PWR Sense line * R16 - Change from 10k to 100k - to measure correct battary volrage values * NTC Add termal pin to battary connector
USB Inpur Protection
GPIO Solder Points
R-PROG 10k => 130 mA 5k => 250 mA 4k => 300 mA 1k5 => 780 mA 1k2 => 1000 mA
Automatic Programmer
Motor Driver
Battery Charge Protection
Automatic programmer conditions
PWR ADC 4.2V 1V 3,3V 0,7858V
USB Serial
Power Button
Battery Voltage Sense
SENSE 0.4V
GPIO 0
Battery Discharge Protection
3V3 LDO

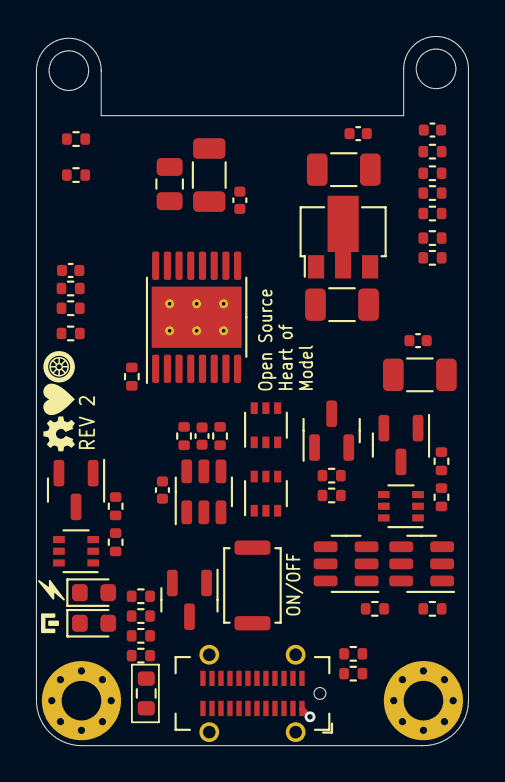
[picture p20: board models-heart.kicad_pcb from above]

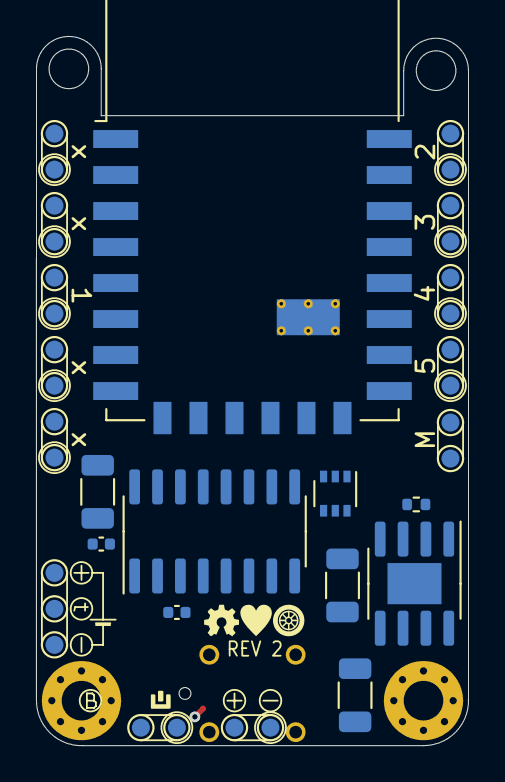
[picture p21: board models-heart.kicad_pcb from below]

Board: 4 copper layers, 24.0 x 39.4 mm, 99 parts (37 on the bottom side), 56 nets.

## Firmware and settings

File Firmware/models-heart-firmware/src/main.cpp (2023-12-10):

#include <Arduino.h>
#include <ESP8266WiFi.h>
#include <WiFiClient.h>
#include <ESP8266WebServer.h>
#include <ESP8266SSDP.h>
#include <DNSServer.h>
#include <ESP8266mDNS.h>
// #include <FS.h>
#include <LittleFS.h>
#include <Json.h>
#include <Motor.h>
#include <Blinker.h>
#include <PowerManager.h>
#include <Collection.h>
#include <ui.h>
#include <ScriptEngine.h>
#include <WebUIController.h>
#include <Joypad.h>
#include <SetupController.h>
#include <FileServer.h>

PowerManager powerManager(PIN_POWER_HOLD, PIN_POWER_SENSE, PIN_BATTERY_SENSE);

// JsonObject ui = JsonObject();
JsonObject scripts = JsonObject();
JoypadCollection joypads = JoypadCollection();
ScriptEngine engine = ScriptEngine();

char SSID[32] = "MODELS_HEART";
char SSID_password[20] = "12345678";
IPAddress apIP = IPAddress(192, 168, 4, 1);
IPAddress netMsk = IPAddress(255, 255, 255, 0);

const byte DNS_PORT = 53;
DNSServer dnsServer = DNSServer();

int testNumber = 0;

static void powerButton_Click(void *sender)
{
    testNumber++;
    if (testNumber == 10)
        testNumber = 0;
}

static void onPowerOff(void *sender)
{
    engine.SaveState("/state.json");
    digitalWrite(LED_BUILTIN, HIGH);
}

void EventSourceName()
{
    Serial.println(webServer.uri());
    webServer.sendHeader("Cache-Control", "no-cache, no-store, must-revalidate");
    webServer.sendHeader("Pragma", "no-cache");
    webServer.sendHeader("Expires", "-1");
    webServer.setContentLength(CONTENT_LENGTH_UNKNOWN);

    Joypad *j = new Joypad();
    j->client = webServer.client();
    j->clientIP = webServer.client().remoteIP();
    joypads.add(j);

    String ret = "http://" + apIP.toString() + ":80/api/events?{\"client\":\"" + String(j->id) + "\"}";
    yield();
    webServer.send(200, "text/plain", ret);
    Serial.println(ret);
}

void Events()
{
    Serial.println(webServer.uri());
    WiFiClient client = webServer.client();

    String s = webServer.argName(0);
    JsonString json = "";
    json += s;
    int id = json.getInt("client");

    // console.printf("client:%i", id);

    Joypad *j = joypads.getById(id);
    if (j == nullptr)
    {
        Serial.printf("Unauthorized client %i\n", id);
        webServer.handleNotFound();
        return;
    }
    if (client.remoteIP() != j->clientIP)
    {
        Serial.printf("wrong IP", id);
        joypads.remove(j);
        webServer.handleNotFound();
        return;
    }
    j->client = client;
    client.setNoDelay(true);
    client.setSync(true);
    webServer.setContentLength(CONTENT_LENGTH_UNKNOWN); // the payload can go on forever
    webServer.sendContent_P(PSTR("HTTP/1.1 200 OK\nContent-Type: text/event-stream;\nConnection: keep-alive\nCache-Control: no-cache\nAccess-Control-Allow-Origin: *\n\n"));
    Serial.flush();
}

void Post()
{
    if (webServer.hasArg("plain"))
    {
        String s = webServer.arg("plain");
        JsonString json = "";
        json += s;
        int id = json.getInt("client");

        // console.printf("client:%i\n", id);

        Joypad *j = joypads.getById(id);
        if (j == nullptr)
        {
            webServer.handleNotFound();
            return;
        }
        webServer.Ok();
        if (j->processFieldsFormat(&json))
        {
            joypads.populateValuesTo(j);
        }
        else if (j->processParcel(&json))
        {
            joypads.updateValuesFrom(j);
        }
    }
    else
    {
        webServer.Ok();
    }
}

void LoadValues()
{
    if (webServer.hasArg("client"))
    {
        String s = webServer.arg("client");
        int id = s.toInt();
        Joypad *j = joypads.getById(id);
        if (j == nullptr)
        {
            Serial.printf("Unauthorized client %i\n", id);
            webServer.handleNotFound();
            return;
        }
        JsonString ret = "";
        ret.beginObject();
        ret.AddValue("tran", String(1));
        ret.beginArray("values");
        if (j->fields != nullptr)
        {
            Joypadfield *f = (Joypadfield *)(j->fields->getFirst());
            while (f != nullptr)
            {
                ret.appendComa();
                int v = f->value;
                ret += "\"" + String(v) + "\"";
                f->sent = f->value;
                f = (Joypadfield *)(f->next);
            }
        };
        ret.endArray();
        ret.endObject();
        Serial.print("LoadValues: ");
        Serial.println(ret);
        webServer.jsonOk(&ret);
    }
}

void setupController_buildConfig(JsonString *json)
{
    json->beginObject();
    json->AddValue("ssid", SSID);
    json->AddValue("password", SSID_password);
    json->endObject();
}

void setupController_saveParameter(String name, String value)
{
    if ((name).equalsIgnoreCase("ssid"))
    {
        strncpy(SSID, (value + "\0").c_str(), value.length() + 1);
    }

    if ((name).equalsIgnoreCase("password"))
    {
        strncpy(SSID_password, (value + "\0").c_str(), value.length() + 1);
    }
}

void SaveConfig()
{
    JsonString cfg = JsonString("");
    setupController_buildConfig(&cfg);
    File f = LittleFS.open("/settings.json", "w");
    f.print(cfg);
    f.flush();
    f.close();
    Serial.println(cfg);
}

void LoadConfig()
{
    if (LittleFS.exists("/settings.json"))
    {
        File f = LittleFS.open("/settings.json", "r");
        JsonString cfg = JsonString(f.readString().c_str());
        setupController_saveParameter("ssid", cfg.getValue("ssid"));
        setupController_saveParameter("password", cfg.getValue("password"));
        f.flush();
        f.close();

        cfg = JsonString("");
        setupController_buildConfig(&cfg);
        Serial.println(cfg);
    }
    else
    {
        Serial.println("load default config");
    }
}

void setupController_saveConfig(JsonString *json)
{
    SaveConfig();
}

void ui_Get()
{
    webServer.handleFileRead("/ui.json", false, false);
}

unsigned int startEvent;
unsigned int stopEvent;
unsigned int connectedEvent;
unsigned int disconnectedEvent;
unsigned int autoEventTimeout = 3000;

void onConnected()
{
    Serial.println("onConnected()");
    connectedEvent = millis();
    engine.command("connected", 1);
}

void onDisconnected()
{
    Serial.println("onDisconnected()");
    disconnectedEvent = millis();
    engine.command("disconnected", 1);
}

void onStart()
{
    startEvent = millis();
    engine.command("start", 1);
}

void onStop()
{
    stopEvent = millis();
    engine.command("stop", 1);
}

void setup()
{
    // analogWriteFreq(6000);
    powerManager.begin();
    powerManager.OnPowerPress = powerButton_Click;
    powerManager.OnPowerOff = onPowerOff;
    powerManager.bat_percent_critical = 20;

    powerManager.bat_adc_min = 800;
    powerManager.bat_adc_max = 1024;
    pinMode(PIN_POWER_SENSE, INPUT);

    Serial.begin(115200);
    Serial.println("");
    Serial.println("");
    Serial.println("Open Source Model's Heart");
    pinMode(LED_BUILTIN, OUTPUT);
    digitalWrite(LED_BUILTIN, LOW);
    powerManager.powerOn();
    Serial.println("Power Manager is holding power On. You can releas power button.");

    if (!LittleFS.begin())
    {
        Serial.println(F("No file system!"));
        Serial.println(F("Fomating..."));
        if (LittleFS.format())
            Serial.println(F("OK"));
        else
        {
            Serial.println(F("Fail.... rebooting..."));
            while (true)
                ;
        }
    }
    LoadConfig();

    if (LittleFS.exists("/scripts.json"))
    {
        Serial.println("Parsing scripts.json");
        File f = LittleFS.open("/scripts.json", "r");
        scripts.load(&f);
        f.close();
    }

    engine.build(&scripts);
    engine.LoadState("/state.json");

    Item *itm = engine.elements->getFirst();
    while (itm != nullptr)
    {
        ScriptElement *el = ((ScriptElement *)itm);
        if (el->type == ScriptElementTypes::click)
        {
            joypads.setValue(el->cmd, el->state);
        }
        itm = itm->next;
    }

    Joypadfield *fld = joypads.getFirstField();
    JsonString json = "";
    json.beginObject();
    while (fld != nullptr)
    {
        json.AddValue(fld->name, String(fld->value));
        fld = (Joypadfield *)(fld->next);
    }
    json.endObject();

    Serial.print(json);

    WiFi.begin();
    WiFi.disconnect();
    WiFi.mode(WIFI_AP);
    WiFi.softAP(SSID, SSID_password);

    /* Setup the DNS server redirecting all the domains to the apIP */
    dnsServer.setErrorReplyCode(DNSReplyCode::NoError);
    dnsServer.start(DNS_PORT, "*", apIP);

    Serial.println("");
    Serial.println(apIP.toString());

    // Serial.println("webServer.setup()");
    webServer.console = &Serial;
    webServer.setup();
    // Serial.println("OK");
    webServer.on("/api/EventSourceName", EventSourceName);
    webServer.on("/api/events", Events);
    webServer.on("/api/post", HTTPMethod::HTTP_POST, Post);
    webServer.on("/api/loadValues", HTTPMethod::HTTP_GET, LoadValues);

    setupController.buildConfig = setupController_buildConfig;
    setupController.saveParameter = setupController_saveParameter;
    setupController.saveConfig = setupController_saveConfig;
    setupController.setup();

    fileServer.setup();

    webServer.on("/api/ui", HTTPMethod::HTTP_GET, ui_Get);

    onStart();
}

int clientCount = 0;
uint32_t runtime = 0;

void loop()
{
    powerManager.loop();
    dnsServer.processNextRequest();
    joypads.loop();
    webServer.loop();
    engine.loop();
    if (joypads.getCount() > 0)
    {
        Joypadfield *jp = joypads.getFirstField();
        while (jp != nullptr)
        {
            engine.command(jp->name, jp->value);
            jp = (Joypadfield *)(jp->next);
        }
    }
    else
    {
        // noone connected...
    }
    joypads.setValue("bat", powerManager.getBattaryPercent());
    joypads.setValue("adc", powerManager.getBatteryADC());

    uint32_t seconds = millis() / 1000;
    if (seconds != runtime)
    {
        runtime = seconds;
        joypads.setValue("runtime", runtime);
    }
    int clients = joypads.getCount();

    if (clientCount > clients)
    {
        onDisconnected();
    }
    else if (clientCount < clients)
    {
        onConnected();
    }

    clientCount = clients;

    if (connectedEvent != 0)
    {
        if (millis() - connectedEvent > autoEventTimeout)
        {
            engine.command("connected", 0);
            connectedEvent = 0;
        }
    }

    if (disconnectedEvent != 0)
    {
        if (millis() - disconnectedEvent > autoEventTimeout)
        {
            engine.command("disconnected", 0);
            disconnectedEvent = 0;
        }
    }

    if (startEvent != 0)
    {
        if (millis() - startEvent > autoEventTimeout)
        {
            engine.command("start", 0);
            startEvent = 0;
        }
    }

    if (stopEvent != 0)
    {
        if (millis() - stopEvent > autoEventTimeout)
        {
            engine.command("stop", 0);
            stopEvent = 0;
        }
    }
}

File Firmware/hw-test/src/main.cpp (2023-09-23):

#include <Arduino.h>
#include <Json.h>
#include <Motor.h>
#include <Blinker.h>
#include <board.h>

PowerManager powerManager(PIN_POWER_HOLD, PIN_POWER_SENSE, PIN_BATTERY_SENSE);
PhysicsEffects *motorPhysics = nullptr;
MotorBase *motor = nullptr;
unsigned long motorTestStart = 0;

Blinker *pinBlinker = nullptr;

int testNumber = 0;
int currentTestNumber = 0;

static void powerButton_Click(void *sender)
{
  testNumber++;
  if (testNumber == 10)
    testNumber = 0;
  Serial.print("Test number ");
  Serial.println(testNumber);
}

static void onPowerOff(void *sender)
{
  digitalWrite(LED_BUILTIN, HIGH);
}

void setup()
{
  powerManager.begin();
  powerManager.OnPowerPress = powerButton_Click;
  powerManager.OnPowerOff = onPowerOff;
  pinMode(PIN_POWER_SENSE, INPUT);

  Serial.begin(115200);
  Serial.println("");
  Serial.println("");
  Serial.println("Open Source Model's Heart - Harware Test");
  Serial.println("Wait until release power button.");
  powerManager.powerOn();
  pinMode(LED_BUILTIN, OUTPUT);
  Serial.println("Power Manager is holding power On. You can releas power button.");
  digitalWrite(LED_BUILTIN, LOW);

  pinBlinker = new Blinker("blink");
  pinBlinker->console = &Serial;
  pinBlinker->debug = true;
  pinBlinker->Add(PIN_HEAD_LIGHT, 0, LOW);
  pinBlinker->Add(PIN_HEAD_LIGHT, 0, 255);
  pinBlinker->Add(PIN_HEAD_LIGHT, 500, LOW);
  pinBlinker->Add(PIN_HEAD_LIGHT, 1000, LOW);
}

void stopMotorTest()
{
  if (motor == nullptr)
    return;
  motor->reset();
  motor->loop();
}

void motorTest()
{
  if (motor == nullptr)
  {
    motorPhysics = new PhysicsEffects();
    motor = new HBridge("motor", PIN_MOTOR_A, PIN_MOTOR_B, motorPhysics);
    motor->isEnabled = true;
    motor->responder = &Serial;
    motor->setWeight(80000);
  }
  if ((millis() - motorTestStart) > 12000)
  {
    motorTestStart = millis();
  }
  else if ((millis() - motorTestStart) > 9000)
  {
    motor->setSpeed(0);
  }
  else if ((millis() - motorTestStart) > 6000)
  {
    motor->setSpeed(-255);
  }
  else if ((millis() - motorTestStart) > 3000)
  {
    motor->setSpeed(0);
  }
  else
  {
    motor->setSpeed(255);
  }
  motor->loop();
}

void stopBlinker()
{
  if (pinBlinker != nullptr)
    pinBlinker->end();
}

void startBlinker(int pin)
{
  if (!pinBlinker->isRunning())
  {
    pinMode(pin, OUTPUT);
    BlinkerItem *item = pinBlinker->item(0);
    while (item != nullptr)
    {
      item->pin = pin;
      item = item->next;
    }
    pinBlinker->begin();
  }
  pinBlinker->loop();
}
unsigned long lastBattaryTest = 0;

void testBatteryVoltage()
{
if ((millis() - lastBattaryTest) > 1000){
  lastBattaryTest = millis();
  Serial.printf("Battary ADC %i\n", powerManager.getBatteryADC());
}
}

void loop()
{
  powerManager.loop();
  if (currentTestNumber != testNumber)
  {
    switch (currentTestNumber)
    {
    case 1:
      stopMotorTest();
      break;
    case 2:
      stopBlinker();
      break;
    case 3:
      stopBlinker();
      break;
    case 4:
      stopBlinker();
      break;
    case 5:
      stopBlinker();
      break;
    case 6:
      break;
    default:
      break;
    }
  }
  currentTestNumber = testNumber;
  if (testNumber == 1)
  {
    motorTest();
  }
  if (testNumber == 2)
  {
    startBlinker(PIN_REVERSE_LIGHT);
  }
  if (testNumber == 3)
  {
    startBlinker(PIN_LEFT_TURN_LIGHT);
  }
  if (testNumber == 4)
  {
    startBlinker(PIN_RIGHT_TURN_LIGHT);
  }
  if (testNumber == 5)
  {
    startBlinker(PIN_HEAD_LIGHT);
  }
  if (testNumber == 6)
  {
    testBatteryVoltage();
  }
}

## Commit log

2023-07-20 Layout REV1
    [models-heart.kicad_pcb, models-heart.kicad_sch]
2023-07-22 minor fixes
    [models-heart.kicad_pcb, models-heart.kicad_sch]
2023-07-22 Release candidate
    [models-heart.kicad_pcb, models-heart.kicad_sch]
2023-07-24 Trace Almost Done
    [models-heart.kicad_pcb, models-heart.kicad_sch]
2023-07-26 PCB Done
    [models-heart.kicad_pcb, models-heart.kicad_sch]
2023-07-29 Update image files
    [models-heart.kicad_pcb]
2023-07-29 update board render
2023-08-12 Production Complete
    [cpl-correction.xlsx, cpl.xlsx, models-heart-B_Cu.gbr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]
2023-08-19 Part 5
    [models-heart-B_Cu.gbr, models-heart-B_Mask.gbr, models-heart-B_Paste.gbr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]
2023-08-29 Rev 1
    [models-heart.kicad_sch]
2023-08-29 Тестові налаштування
    [models-heart.kicad_pcb]
2023-09-03 ui prototype
2023-09-09 зфке 8
2023-10-04 actionns test
    [models-heart.kicad_pcb, models-heart.kicad_sch]
2023-10-12 куфвьу
2023-10-25 Add Toggle button
2023-11-25 power cutoff
    [models-heart.kicad_sch]
